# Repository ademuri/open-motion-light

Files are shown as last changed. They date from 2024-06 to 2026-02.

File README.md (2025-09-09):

# open-motion-light

A battery-powered motion sensor light.

Status: in development (as of July 2025). The current hardware revision, v1.2, mostly works, but has a few small issues. I'm hoping that the next revision will be the "final" version before starting small-scale production for sale.

Ordering and programming one of these units is a relatively complicated project. I don't recommend it unless you're looking for a learning experience, or have completed similar projects before.

## Programming

To easily update the firmware on your unit, and to configure the settings, go to the management page: https://ademuri.github.io/open-motion-light-manager/. This uses the WebSerial browser API, which is only supported in Chromium-based browsers (e.g. Chrome and Edge).

Otherwise, you can build the code yourself using PlatformIO. To build and upload, from the root of this directory run:

```bash
$ pio run -e default -t upload
```

## Firmware

The firmware for this project is written in C++ using the Arduino framework, and built using PlatformIO. It has comprehensive test coverage, which runs on the desktop (also using PlatformIO). You can run the tests with:

```bash
$ pio test -e native
```

### Architecture

Most use of hardware is wrapped in a hardware abstraction layer (HAL) - a thin wrapper class. This allows writing simple fakes for each of these interfaces, for use in tests. This means that the primary control logic is easily testable.

## Fabrication

This board is designed for PCB fabrication and assembly using JLC PCB. The relevant files are in `hardware/production`:

- `open-motion.light.zip` contains the Gerbers, for PCB assembly.
- `bom.csv` is the bill of materials, which contains the list of components.
- `positions.csv` is the positions file - it lists the exact position and orientation of all placed components.

### PCB parameters

Most of JLC's defaults for PCBs are fine. 1.6mm is the best size for this. White soldermask is preferred, since it reflects more light. I highly recommend selecting the 'LeadFree HASL' surface finish - better not to use lead, and it's only a small cost increase.

### Assembly parameters

This design requires PCBA Type 'Standard', since it needs assembly on both sides. Most of the components are on the top, except the USB port, battery holder, power switch, and reset button. For small quantities, this adds moderate cost, but the USB port would be difficult (although not impossible) to solder by hand. The rest of the parameters can be left as default.

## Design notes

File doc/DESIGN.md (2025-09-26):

# Design record

## Hardware v1.1 measurements - LED driver

Signal rise time is ~85ns, which is about 10MHz. No overshoot or ringing visible on a 50MHz scope.

At 3.5v, with main LED full on the board draws ~340mA. This increases to ~390mA at 3.2v, and ~440mA at 3.0v.

## Hardware v1.3 calculations

### PIR sensitivity adjust

The `SENS` pin is used to adjust the sensitivity of the motion sensor. 0V is maximum sensitivity, and 1/4 _ VDD is minimum. In this revision, the PIR is powered by a 3.0V LDO, so the minimum sensitivity will be at 1/4 _ 3.0V = 0.75V.

The PIR `SENS` pin has an equivalent 120kΩ pulldown (measured on two devices, pretty consistent, at least at the same temperature). I added a 1MΩ pulldown resistor to improve stability across PIR devices and temperatures. This pulldown likely comes from the PIR's internal ADC.

To allow adjusting sensitivity in software, three resistors are connected to the pulldown via MCU pins. These form a variable voltage divider. They're sized at 1MΩ and 2MΩ. This means that the possible resistance and voltage divider output values (at 3.4V battery level) are:

| Resistance | Output Voltage | Percent |
| --- | --- | --- |
| 2 MΩ | 173 mV | 23% |
| 1 MΩ | 329 mV | 44% |
| 667 kΩ | 470 mV | 63% |
| 400 kΩ | 718 mV | 96% |

There could be moderate variation in the PIR's equivalent pulldown between devices and at different temperatures. The sensitivity adjustment is pretty coarse anyway, so this is acceptable. If this does prove to be an issue, we could use a low-power voltage buffer, such as `TLV8541DBVR`, which consumes 500nA.

### Battery charger temperature sensor

The `BQ25170DSGR` uses an NTC thermistor to measure the temperature of the battery, and will only charge when the temperature is in a certain range. [The battery that I've used so far](https://www.batteryspace.com/LiFePO4-18650-Rechargeable-Cell-3.2V-1800-mAh.aspx) may be charged between 0°C and 50°C. Since the thermistor is just surface-mounted to the PCB, and not in direct contact with the battery, we'll adjust this range to roughly 5°C-45°C.

From [the charger IC datasheet](https://www.ti.com/lit/ds/symlink/bq25170.pdf), the nominal bias current is 38μA. `V_COLD` is 1.04V, and `V_HOT` is 188mV. So, the resistances we need are:

- Cold: `1.04V / 38μA = 27368Ω`
- Hot: `.188V / 38μA = 4947Ω`

If we use [this Sunlord 10k 3950K thermistor](https://jlcpcb.com/partdetail/Sunlord-SDNT1608X103F3950FTF/C279936), then it will yield the range 4°C-42°C - close enough!

We can disable charging by pulling the TS pin below 40mV (minimum). We'll connect this to an MCU pin. Most of the pins have 50nA leakage, which is negligible relative to the 38μA bias current. If we ignore the resistance of the thermistor, then we need `.04V / 38μA = 1052Ω` at most. So, if we use a 1kΩ resistor, it'll be sufficient.

### LED driver inductor selection

[From the datasheet](https://www.ti.com/lit/ds/symlink/tps61165.pdf), inductor peak-to-peak ripple is:

`I_P = 1 / (22uH * 1.2MHz * (1 / (19V + 0.4V - 3V) + 1 / 3V)) = 111mA`

assuming a 22nH inductor, and 3.6V input voltage (worst case). The following calculations assume 80% efficiency - the datasheet doesn't list the efficiency for 3V in, 19V out. But, for 5V in, 24V out at 48mA, the efficiency is ~89%. And, for 3V in, 12V out at 48mA, the efficiency is ~88%. So, actual efficiency should be closer to these values.

`I_out-max = 3V * (1.2A - 0.111A / 2) * 0.8 / 19V = 144.5 mA`

We're setting the output current to `48 mA`, so we're well within a safe margin.

`I_in-DC = 19V * .048A / (3V * 0.8) = 380 mA`

The inductor needs to be rated for a saturation current of greater than `380mA + 111mA / 2 = 436mA`.

### Part availability and sourcing

The previous revision used a few ICs from Chinese brands, which I couldn't find a source for other than LCSC. This presents moderate risk - if LCSC stops carrying them, then we'd need to use a different part, likely requiring a redesign.

#### USB-to-serial converter

The previous revision used the CH340X USB-to-UART serial converter chip. While this chip is commonly used, it is not available from Western retailers such as Digikey and Mouser. It _is_ available through LCSC, a reputable Chinese supplier. I found it at [another Chinese supplier, HQOnline](https://www.hqonline.com/product-detail/usb-chips-wch-ch340x-2500405741) - owned by NextPCB. While I'm not familiar with them, it's at least a second source. There is still some risk from using parts only available from Chinese distributors, such as from export restrictions or tariffs.

Sparkfun uses the CH340 series in some of their products - see [their guide on installing the drivers](https://learn.sparkfun.com/tutorials/how-to-install-ch340-drivers/all). This is a decent sign that it's available enough. I also found [this thread on EEVblog](https://www.eevblog.com/forum/beginners/ch340-ch330-for-commercial-crowdfunding-product/), where multiple people report using CH340s successfully in their projects.

An alternative would be the [Silicon Labs CP2102N](https://www.digikey.com/en/products/detail/silicon-labs/CP2102N-A02-GQFN28R/9863480). However, the chip is larger (QFN28 vs MSOP-10), and about twice the cost ($1.03 vs $0.39 at qty 100 from LCSC, at revision time).

#### 18650 battery holder

The design uses the [`BH-18650-A1AJ005` 18650 holder](https://jlcpcb.com/partdetail/MYOUNG-BH_18650A1AJ005/C5290176) from manufacturer MYOUNG. The only primary source I could find this from was LCSC. However, JLC doesn't currently list 18650 holders from any other manufacturers, so we'll stick with this as long as we're using JLC's turnkey assembly service. While it may take a layout update if we need to switch to a different holder, the functionality will not change, so this is lower risk.

#### Tactile switch

The design uses a tactile switch for the reset button. This shouldn't strictly be needed, since the CH340X can reset the MCU. However, it is nice to have, and is very cheap (about $0.02 each). This is available both from LCSC and HQOnline, and as with the battery holder, would be straightforward to replace if necessary.

#### White LEDs

As with the above parts, the white LEDs (`HL-AM-2835H421W-S1-08-HR3` from HONGLITRONIC) are not available from Western distributors. However, they are a common size (2835 metric) with common specs (~3.2V forward voltage, 60mA rated current), and [drop-in alternatives](https://www.digikey.com/en/products/detail/ams-osram-usa-inc/GW-JTLMS1-CM-G7H2-XX58-1-60-R33/13680961) are easily available from Western distributors.

#### PIR sensor

The design uses a PIR sensor, `XYC-PIR224S-S1` from NewOpto. This part is not available from Western distributors, and I couldn't find it from Asian distributors other than LCSC. If we limit this to only complete modules with a digital interface, then the cheapest Western-available part is the [ZiLOG `ZDP323`](https://www.mouser.com/ProductDetail/ZiLOG/ZDP323B1). As of writing, it is $2.57 each at qty 100, versus $0.47 each at qty 100 for the NewOpto. From what I can tell, using an analog sensor and implementing the supporting circuitry needed would be pretty complex, and not significantly cheaper anyway. So, we'll stick with the NewOpto for now, and revisit if it becomes a problem.

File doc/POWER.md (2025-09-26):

# Power

## Battery

By default, the MCU that we're using has brown-out reset (BOR) enabled, and configured to use a threshold from 2.54 to 2.74 V. This is documented in the programming manual (RM0377), in section `6.2.2 Brown out reset (BOR)`. Note that with regards to BOR, there are two versions of the processor: one which enables it by default at power-on time, and one which disables it. We want the former.

### Charging

On 2025-09-26, used a thermal camera to check battery charging with hardware v1.3. After about 10 minutes charging a depleted battery, measured a peak temperature of ~126F (52C) on top of the charger IC, and about 106F on the back side of the PCB.

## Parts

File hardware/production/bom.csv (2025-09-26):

Designator | Footprint | Quantity | Value | LCSC Part #
BT1 | BAT-TH_BH-18650-A1AJ005 | 1 | Battery_Cell | C5290176
C1, C13, C19 | 1206 | 3 | 47uF | C96123
C10, C20, C21, C24, C3, C4, C8 | 0603 | 7 | 10uF | C96446
C11 | 1206 | 1 | 4.7uF 50V | C51205
C12, C14, C15, C16, C17, C18, C2, C22, C23, C25, C26, C27, C28, C5, C6, C7, C9 | 0402 | 17 | 100nF | C307331
D1 | SOT-23-6 | 1 | SRV05-4-P-T7 | C85364
D13, D8 | D_SMA | 2 | D | C22452
D2, D3, D4 | 0603 | 3 | RED | C2286
D5, D6, D7 | D_SOD-523 | 3 | ESD5Z5.0 | C5199848
F1 | 1206 | 1 | BSMD1206-075-6V | C883127
FB1, FB2 | 1206 | 2 | 0R | C17888
J1 | HRO_TYPE-C-31-M-12 | 1 | TYPE-C-31-M-12 | C165948
L2 | L_Sunlord_SWPA4030S | 1 | 22uH | C83472
LED1, LED2, LED3, LED4, LED5, LED6 | LED-SMD_L3.3-W2.8-RD | 6 | HL-AM-2835H421W-S1-08-HR3 | C210315
R1 | 0603 | 1 | 620 | C23220
R11, R12, R3, R30, R31, R6, R7 | 0402 | 7 | 10k | C25744
R13, R14, R15, R16, R2, R26, R27, R34, R8, R9 | 0402 | 10 | 1k | C11702
R18 | 0402 | 1 | 100k | C25741
R19, R20, R23 | 0402 | 3 | 4k7 | C25900
R21, R28, R29, R35, R36 | 0603 | 5 | 2M | C22976
R24, R39 | 0402 | 2 | 22k | C25768
R25 | 0603 | 1 | 4Ω3 | C2933230
R37 | 0402 | 1 | 10 | C25077
R4, R5 | 0402 | 2 | 5k1 | C25905
R40, R41, R42 | 0603 | 3 | 1M | C22935
R43 | 0402 | 1 | 82k | C2909388
SW1 | SW_TACTILE_5.1MM_TS-1187A-C-D-B | 1 | SW_Push | C318884
SW3 | SW-SMD_SSSS213800 | 1 | SSSS213800 | C361168
TH1 | 0603 | 1 | Thermistor_NTC | C279936
U1 | Texas_DSG0008A_WSON-8-1EP_2x2mm_P0.5mm_EP0.9x1.6mm_ThermalVias | 1 | BQ25170DSGR | C5208201
U2 | SENSOR-SMD_VCNL4020-GS08 | 1 | VCNL4020-GS08 | C511034
U3 | WSON-6-1EP_2x2mm_P0.65mm_EP1x1.6mm_ThermalVias | 1 | TPS61165DRV | C122568
U4 | TO-5-4_BD9.2-P2.54_XYC-PIR224D-D0 | 1 | XYC-PIR224S-S1 | C6081347
U6 | MSOP-10_3x3mm_P0.5mm | 1 | CH340X | C3035748
U7 | QFN-32-1EP_5x5mm_P0.5mm_EP3.45x3.45mm | 1 | STM32L051K8Ux | C516778

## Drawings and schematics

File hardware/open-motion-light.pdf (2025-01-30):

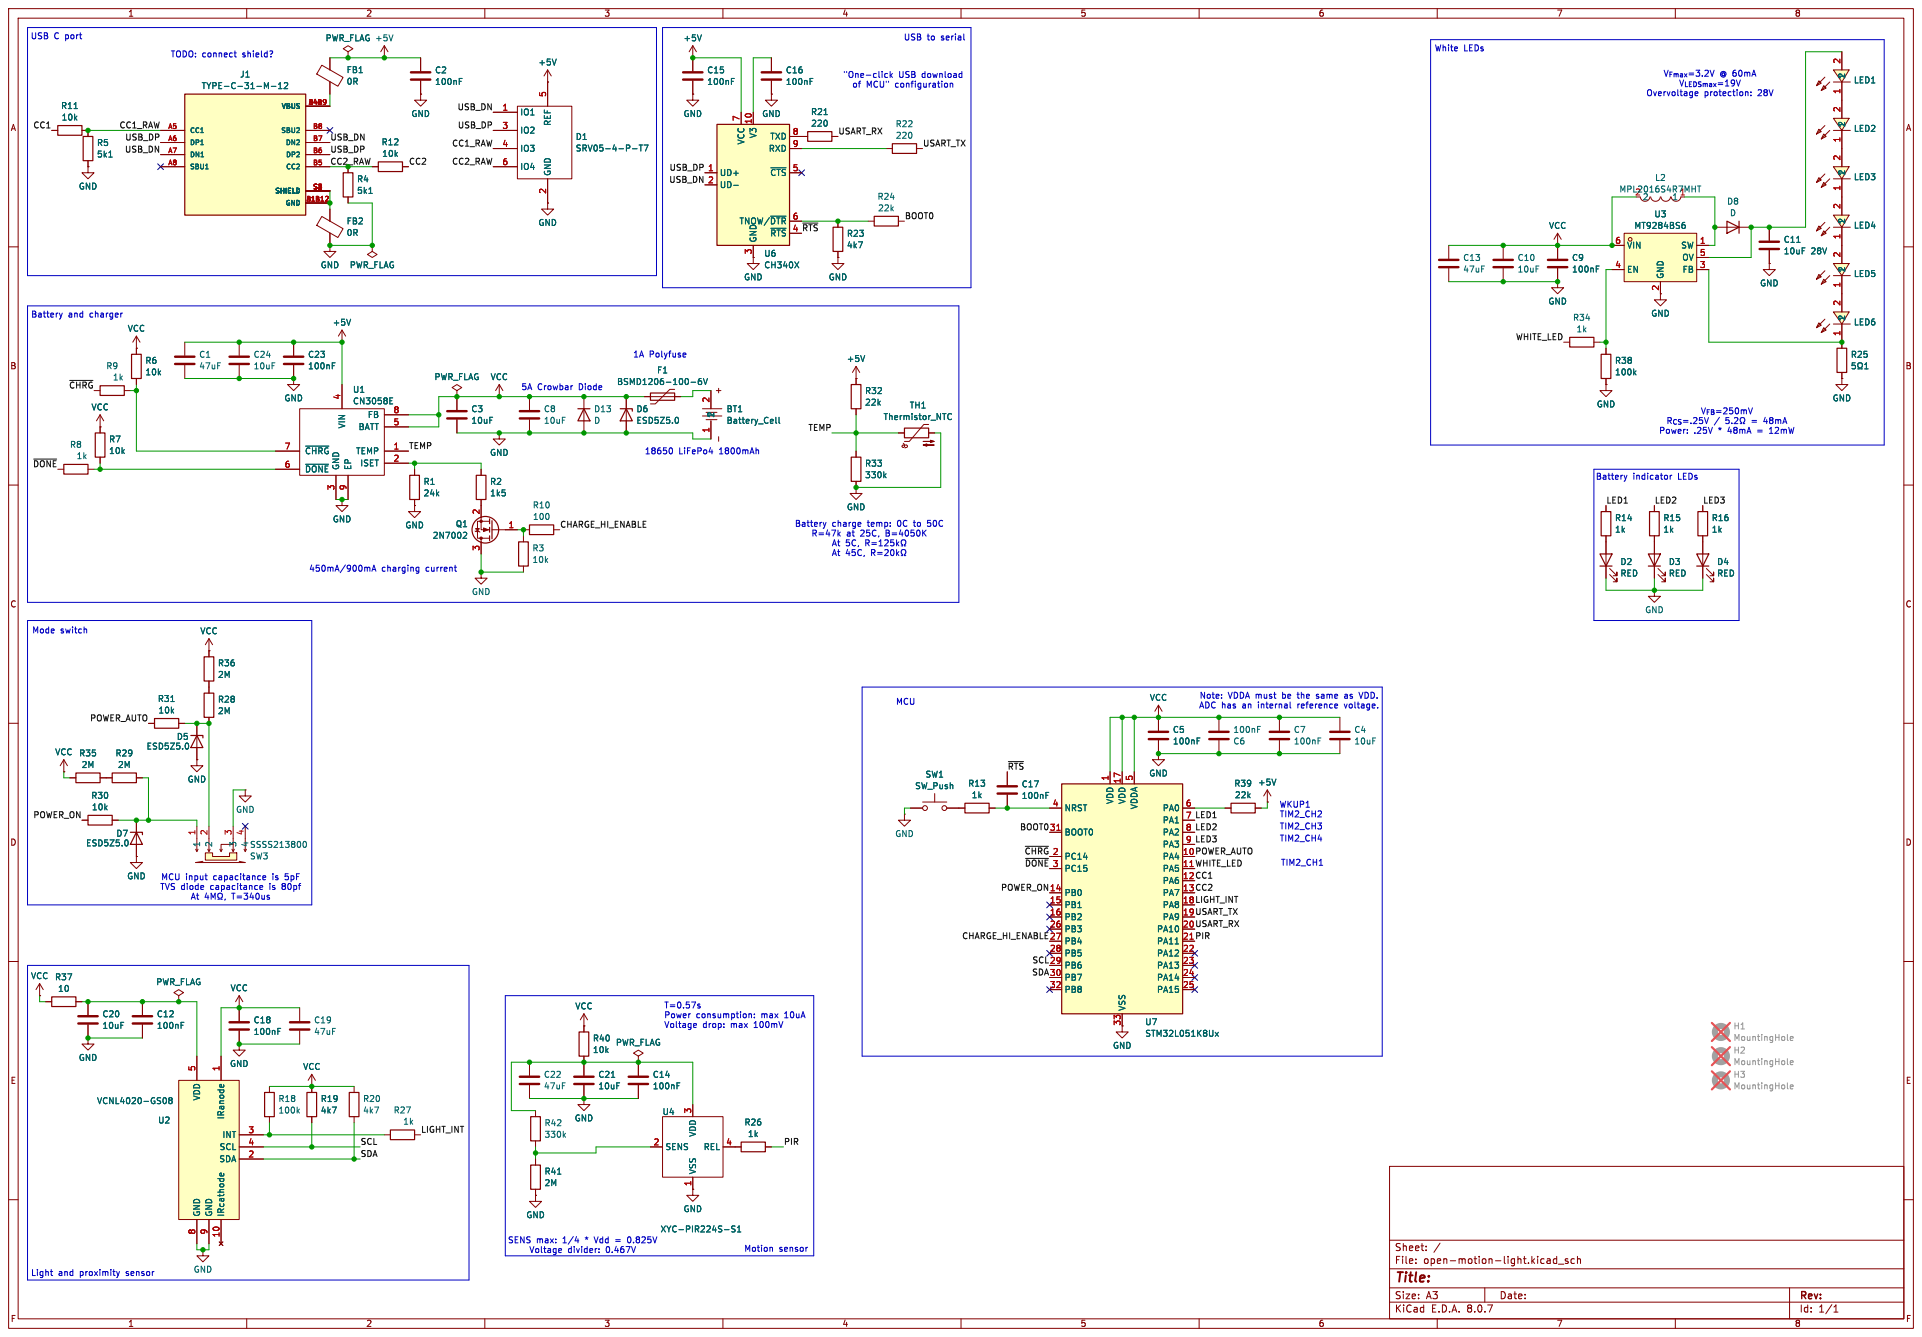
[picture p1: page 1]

of MCU" configuration USB to serial

3 ~{RTS}4 ~{CTS}5 TNOW/~{DTR}6 VCC

4 BATT 5 ~{DONE} 6 ~{CHRG} 7 FB 8 EP

Battery charge temp: 0C to 50C

1 PA4 10 PA5 11 PA6 12 PA7 13 PB0 14 PB1 15 PB2 16 VDD 17 PA8 18 PA9 19 PC14 2 PA10 20 PA11 21 PA12 22 PA13 23 PA14 24 PA15 25 PB3 26 PB4 27 PB5 28 PB6 29 PC15 3 PB7 30 BOOT0 31 PB8 32 VSS 33 NRST 4 VDDA

Id: 1/1 Title: File: open-motion-light.kicad_sch Sheet: /

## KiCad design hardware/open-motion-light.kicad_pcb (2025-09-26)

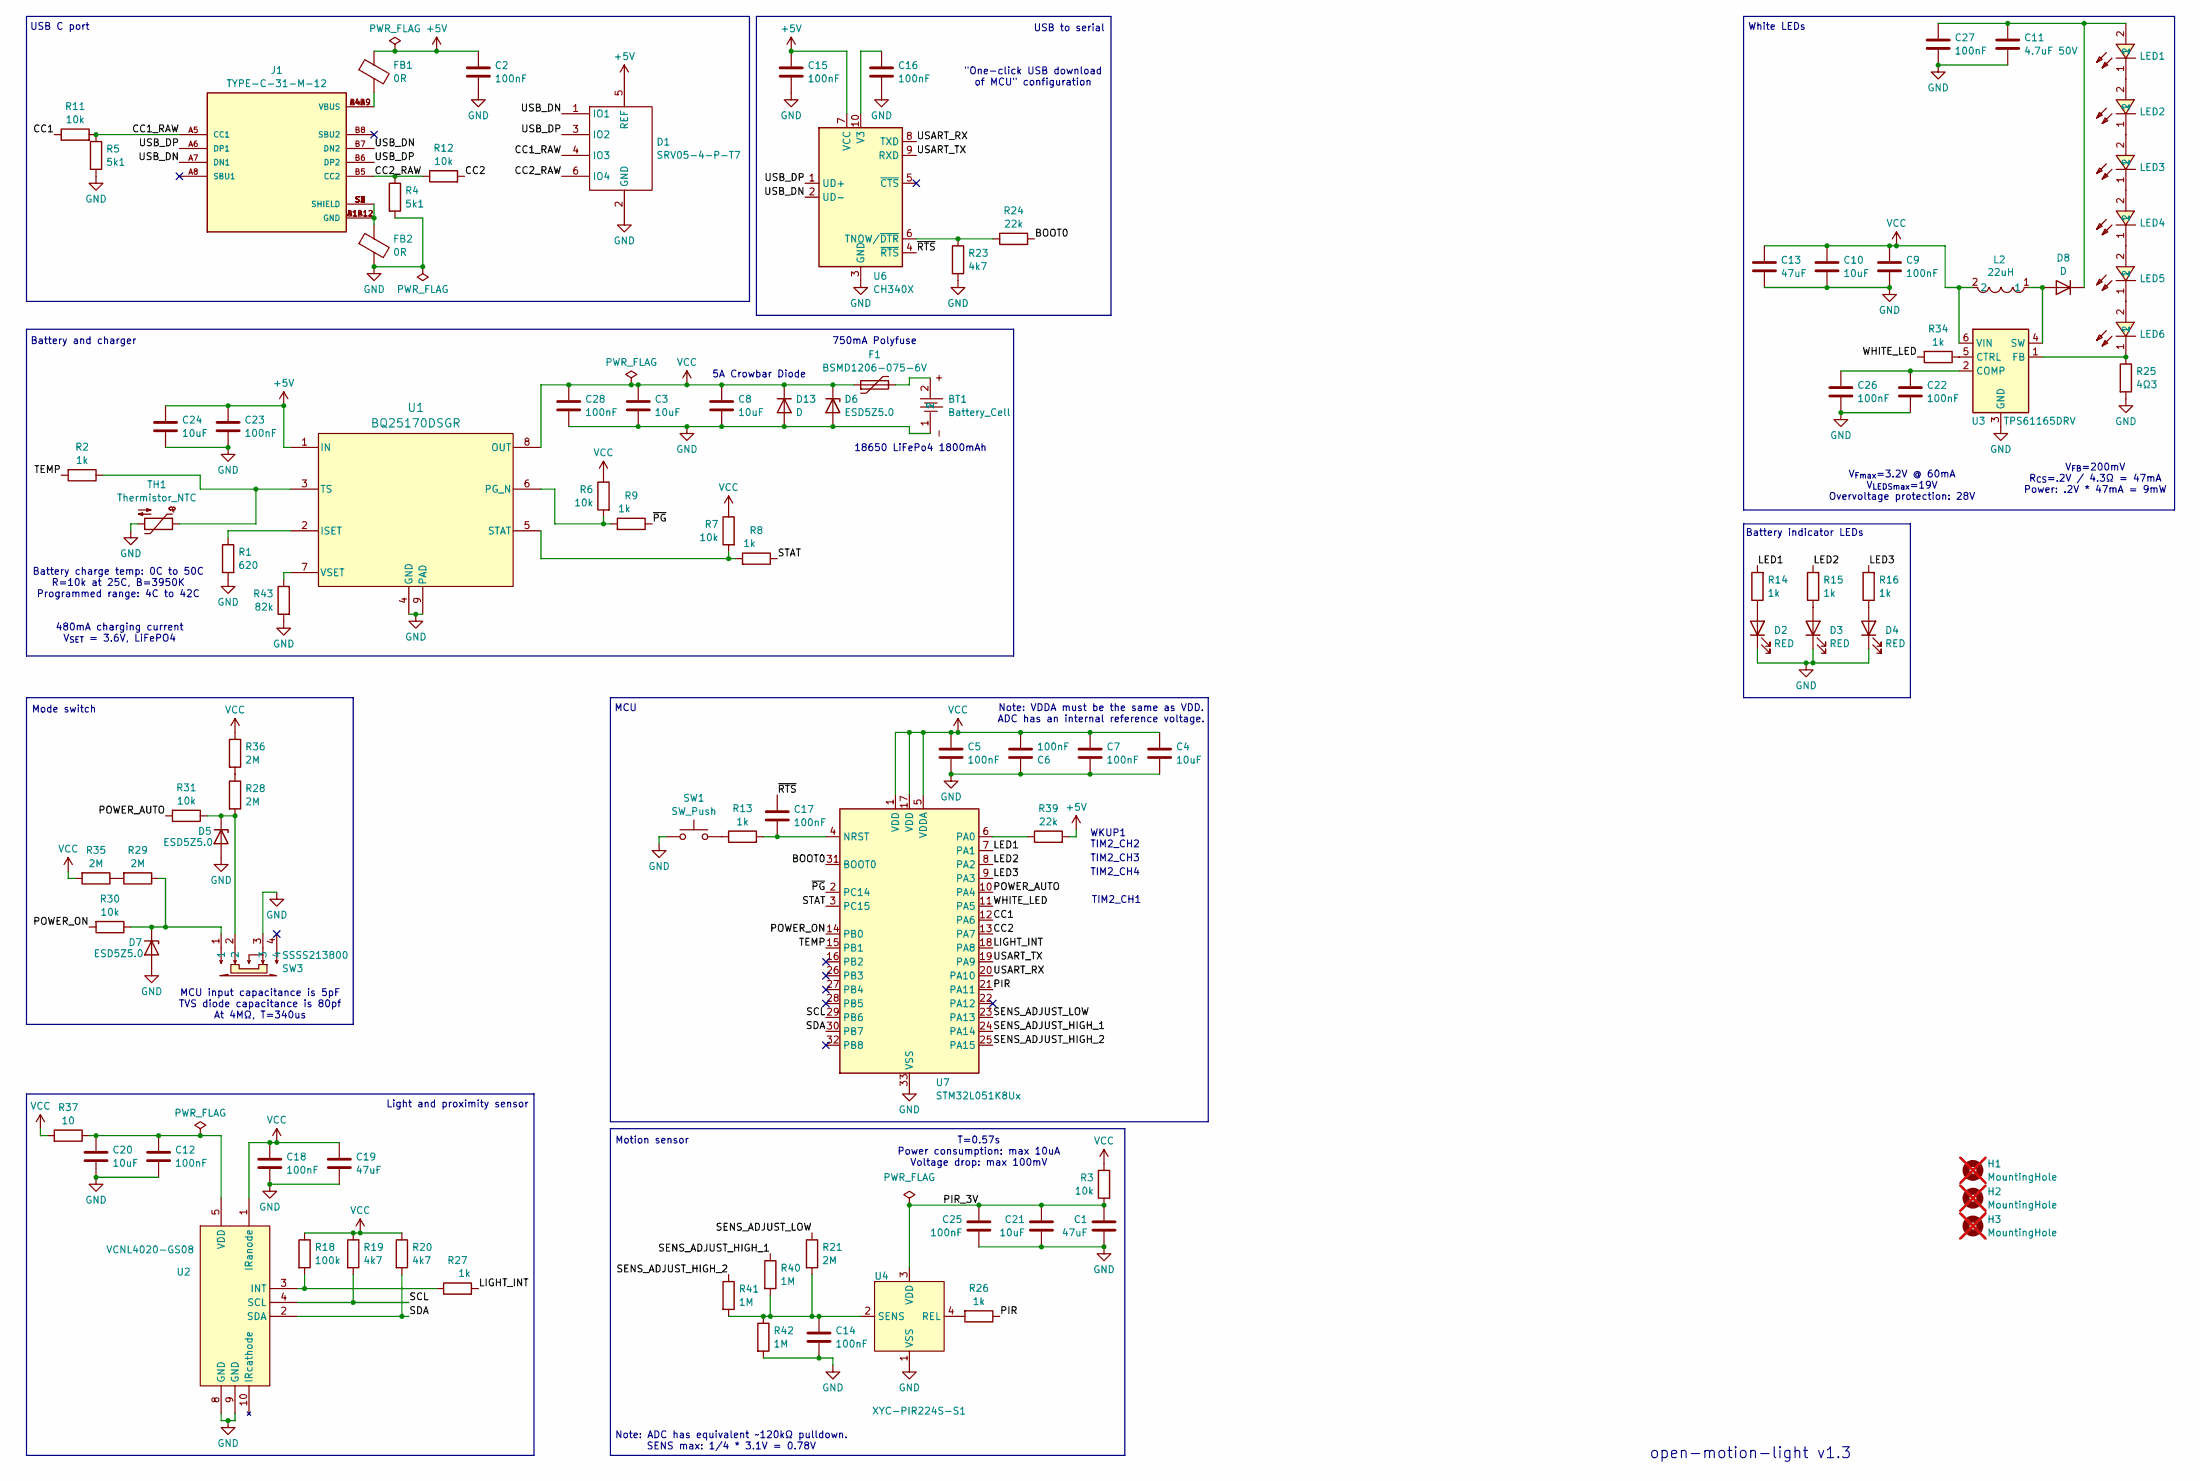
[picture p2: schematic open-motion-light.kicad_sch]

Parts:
BT1: Battery_Cell; BAT-TH_BH-18650-A1AJ005; LCSC Part C5290176
C1, C13, C19: 47uF; C_1206_3216Metric; LCSC C96123
C2, C5, C6, C7, C9, C12, C14, C15, C16, C17, C18, C22, C23, C25, C26, C27, C28: 100nF; C_0402_1005Metric; LCSC C307331
C3, C4, C8, C10, C20, C21, C24: 10uF; C_0603_1608Metric; LCSC C96446
C11: 4.7uF 50V; C_1206_3216Metric; LCSC C51205
D1: SRV05-4-P-T7; SOT-23-6; LCSC C85364
D2, D3, D4: RED; LED_0603_1608Metric; LCSC C2286
D5, D6, D7: ESD5Z5.0; D_SOD-523; LCSC C5199848
D8, D13: D; D_SMA; LCSC C22452
F1: BSMD1206-075-6V; Fuse_1206_3216Metric; LCSC C883127
FB1, FB2: 0R; L_1206_3216Metric; LCSC C17888
H1, H2, H3: MountingHole; MountingHole_3.2mm_M3_ISO7380; not fitted
J1: TYPE-C-31-M-12; HRO_TYPE-C-31-M-12; PARTREV A; LCSC C165948
L2: 22uH; L_Sunlord_SWPA4030S; LCSC Part C83472
LED1, LED2, LED3, LED4, LED5, LED6: HL-AM-2835H421W-S1-08-HR3; LED-SMD_L3.3-W2.8-RD; LCSC Part C210315
R1: 620; R_0603_1608Metric_Pad0.98x0.95mm_HandSolder; LCSC C23220
R2, R8, R9, R13, R14, R15, R16, R26, R27, R34: 1k; R_0402_1005Metric; LCSC C11702
R3, R6, R7, R11, R12, R30, R31: 10k; R_0402_1005Metric; LCSC C25744
R4, R5: 5k1; R_0402_1005Metric; LCSC C25905
R18: 100k; R_0402_1005Metric; LCSC C25741
R19, R20, R23: 4k7; R_0402_1005Metric; LCSC C25900
R21, R28, R29, R35, R36: 2M; R_0603_1608Metric; LCSC C22976
R24, R39: 22k; R_0402_1005Metric; LCSC C25768
R25: 4Ω3; R_0603_1608Metric; LCSC C2933230
R37: 10; R_0402_1005Metric; LCSC C25077
R40, R41, R42: 1M; R_0603_1608Metric; LCSC C22935
R43: 82k; R_0402_1005Metric; LCSC C2909388
SW1: SW_Push; SW_TACTILE_5.1MM_TS-1187A-C-D-B; LCSC C318884
SW3: SSSS213800; SW-SMD_SSSS213800; LCSC Part C361168
TH1: Thermistor_NTC; R_0603_1608Metric; LCSC C279936
U1: BQ25170DSGR; Texas_DSG0008A_WSON-8-1EP_2x2mm_P0.5mm_EP0.9x1.6mm_ThermalV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; LCSC C5208201
U2: VCNL4020-GS08; SENSOR-SMD_VCNL4020-GS08; LCSC Part C511034
U3: TPS61165DRV; WSON-6-1EP_2x2mm_P0.65mm_EP1x1.6mm_ThermalVias; LCSC C122568
U4: XYC-PIR224S-S1; TO-5-4_BD9.2-P2.54_XYC-PIR224D-D0; LCSC Part C6081347
U6: CH340X; MSOP-10_3x3mm_P0.5mm; LCSC C3035748
U7: STM32L051K8Ux; QFN-32-1EP_5x5mm_P0.5mm_EP3.45x3.45mm; LCSC C516778

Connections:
+5V: C2.1, C15.1, C23.2, C24.1, D1.5 (REF), FB1.1, R39.2, U1.1 (IN), U6.7 (VCC)
/BOOT0: R24.2, U7.31 (BOOT0)
/CC1: R11.1, U7.12 (PA6)
/CC1_RAW: D1.4 (IO3), J1.A5 (CC1), R5.1, R11.2
/CC2: R12.2, U7.13 (PA7)
/CC2_RAW: D1.6 (IO4), J1.B5 (CC2), R4.1, R12.1
/LED1: R14.2, U7.7 (PA1)
/LED2: R15.2, U7.8 (PA2)
/LED3: R16.2, U7.9 (PA3)
/LIGHT_INT: R27.2, U7.18 (PA8)
/PIR: R26.1, U7.21 (PA11)
/PIR_3V: C1.2, C21.1, C25.1, R3.2, U4.3 (VDD)
/POWER_AUTO: R31.2, U7.10 (PA4)
/POWER_ON: R30.2, U7.14 (PB0)
/SCL: R19.2, U2.4 (SCL), U7.29 (PB6)
/SDA: R20.2, U2.2 (SDA), U7.30 (PB7)
/SENS_ADJUST_HIGH_1: R40.1, U7.24 (PA14)
/SENS_ADJUST_HIGH_2: R41.1, U7.25 (PA15)
/SENS_ADJUST_LOW: R21.1, U7.23 (PA13)
/STAT: R8.1, U7.3 (PC15)
/TEMP: R2.2, U7.15 (PB1)
/USART_RX: U6.8 (TXD), U7.20 (PA10)
/USART_TX: U6.9 (RXD), U7.19 (PA9)
/USB_DN: D1.1 (IO1), J1.A7 (DN1), J1.B7 (DN2), U6.2 (UD-)
/USB_DP: D1.3 (IO2), J1.A6 (DP1), J1.B6 (DP2), U6.1 (UD+)
/WHITE_LED: R34.2, U7.11 (PA5)
/~PG: R9.1, U7.2 (PC14)
/~RTS: C17.1, U6.4 (~RTS)
GND: BT1.1, C1.1, C2.2, C3.2, C4.2, C5.2, C6.1, C7.2, C8.2, C9.2, C10.2, C11.2, C12.1, C13.1, C14.2, C15.2, C16.2, C18.1, C19.1, C20.2, C21.2, C22.2, C23.1, C24.2, C25.2, C26.2, C27.2, C28.1, D1.2 (GND), D2.1 (K), D3.1 (K), D4.1 (K), D5.2 (A), D6.2 (A), D7.2 (A), D13.2 (A), FB2.2, R1.2, R4.2, R5.2, R23.2, R25.2, R42.2, R43.2, SW1.1, SW3.3, TH1.2, U1.4 (GND), U1.9 (PAD), U2.8 (GND), U2.9 (GND), U3.3 (GND), U3.7 (GND), U4.1 (VSS), U6.3 (GND), U7.33 (VSS)
unnamed: BT1.2, F1.2
unnamed: D2.2 (A), R14.1
unnamed: D3.2 (A), R15.1
unnamed: D4.2 (A), R16.1
unnamed: D5.1 (K), R28.2, R31.1, SW3.2
unnamed: D7.1 (K), R29.1, R30.1, SW3.1
unnamed: D8.2 (A), L2.1, U3.4 (SW)
unnamed: C11.1, C27.1, D8.1 (K), LED1.2
unnamed: FB1.2, J1.A4B9 (VBUS), J1.B4A9 (VBUS)
unnamed: FB2.1, J1.A1B12 (GND), J1.B1A12 (GND), J1.S1 (SHIELD), J1.S2 (SHIELD), J1.S3 (SHIELD), J1.S4 (SHIELD)
unnamed: LED1.1, LED2.2
unnamed: LED2.1, LED3.2
unnamed: LED3.1, LED4.2
unnamed: LED4.1, LED5.2
unnamed: LED5.1, LED6.2
unnamed: R13.1, SW1.2
unnamed: R28.1, R36.2
unnamed: R29.2, R35.1
unnamed: R1.1, U1.2 (ISET)
unnamed: R6.2, R9.2, U1.6 (PG_N)
unnamed: R7.2, R8.2, U1.5 (STAT)
unnamed: R2.1, TH1.1, U1.3 (TS)
unnamed: R43.1, U1.7 (VSET)
unnamed: R18.2, R27.1, U2.3 (INT)
unnamed: C12.2, C20.1, R37.1, U2.5 (VDD)
unnamed: C22.1, C26.1, U3.2 (COMP)
unnamed: R34.1, U3.5 (CTRL)
unnamed: LED6.1, R25.1, U3.1 (FB)
unnamed: R26.2, U4.4 (REL)
unnamed: C14.1, R21.2, R40.2, R41.2, R42.1, U4.2 (SENS)
unnamed: R23.1, R24.1, U6.6 (TNOW/~DTR)
unnamed: C16.1, U6.10 (V3)
unnamed: C17.2, R13.2, U7.4 (NRST)
unnamed: R39.1, U7.6 (PA0)
VCC: C3.1, C4.1, C5.1, C6.2, C7.1, C8.1, C9.1, C10.1, C13.2, C18.2, C19.2, C28.2, D6.1 (K), D13.1 (K), F1.1, L2.2, R3.1, R6.1, R7.1, R18.1, R19.1, R20.1, R35.2, R36.1, R37.2, U1.8 (OUT), U2.1 (IRanode), U3.6 (VIN), U7.1 (VDD), U7.5 (VDDA), U7.17 (VDD)

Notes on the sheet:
TIM2_CH1
V_{FB}=200mV R_{CS}=.2V / 4.3Ω = 47mA Power: .2V * 47mA = 9mW
Battery and charger
V_{Fmax}=3.2V @ 60mA V_{LEDSmax}=19V Overvoltage protection: 28V
White LEDs
"One-click USB download of MCU" configuration
USB C port
T=0.57s Power consumption: max 10uA Voltage drop: max 100mV
TIM2_CH2
Light and proximity sensor
TIM2_CH4
Battery charge temp: 0C to 50C R=10k at 25C, B=3950K Programmed range: 4C to 42C
480mA charging current V_{SET} = 3.6V, LiFePO4
open-motion-light v1.3
5A Crowbar Diode
18650 LiFePo4 1800mAh
WKUP1
TIM2_CH3
750mA Polyfuse
Mode switch
USB to serial
Note: ADC has equivalent ~120kΩ pulldown. SENS max: 1/4 * 3.1V = 0.78V
Note: VDDA must be the same as VDD. ADC has an internal reference voltage.
Battery indicator LEDs
MCU
Motion sensor
MCU input capacitance is 5pF TVS diode capacitance is 80pf At 4MΩ, T=340us

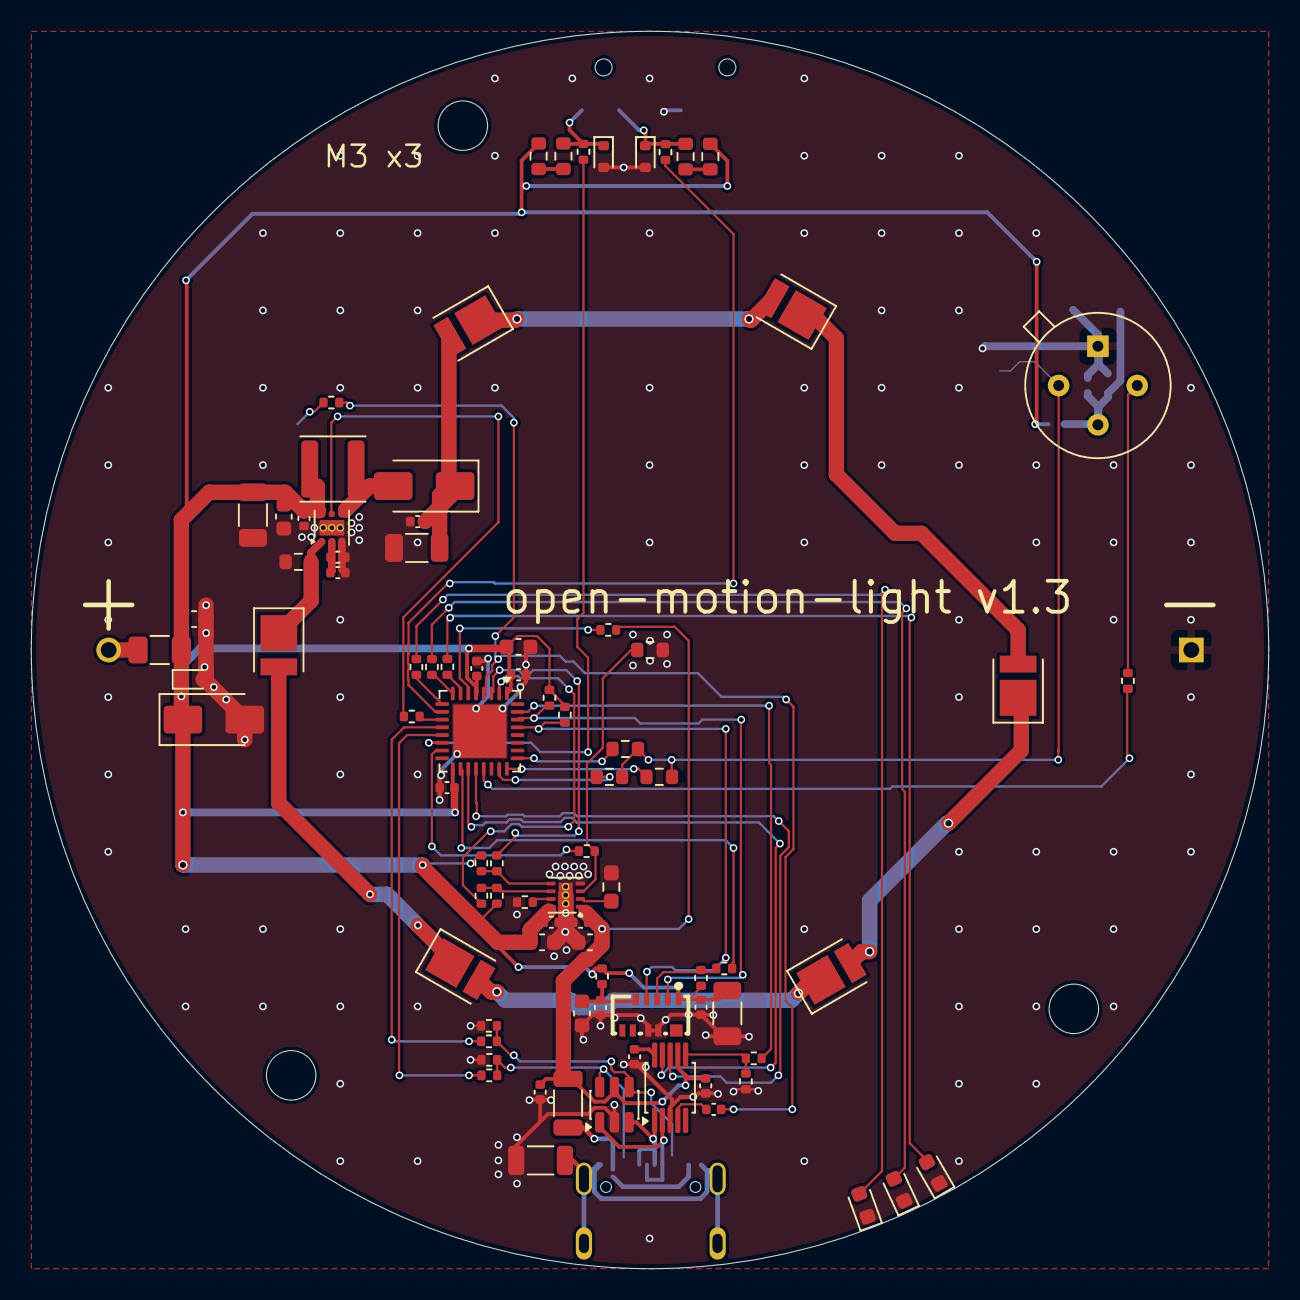
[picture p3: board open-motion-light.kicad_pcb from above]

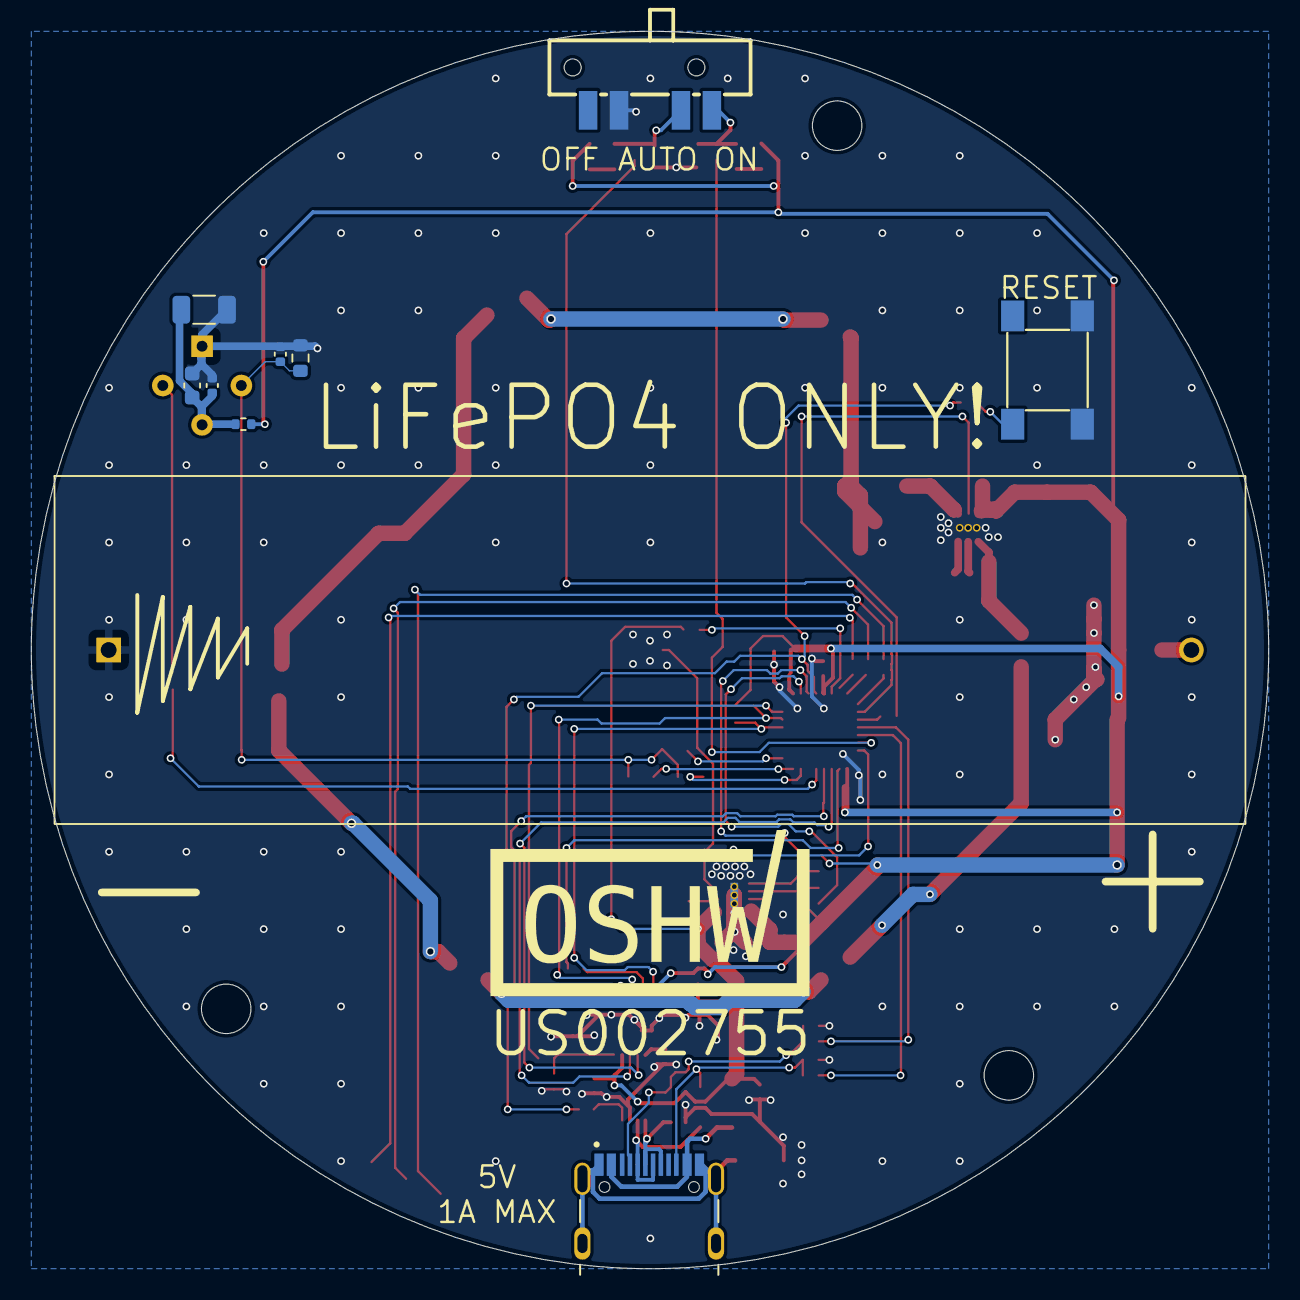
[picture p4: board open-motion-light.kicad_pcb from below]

Board: 4 copper layers, 80.0 x 80.0 mm, 98 parts (10 on the bottom side), 64 nets.

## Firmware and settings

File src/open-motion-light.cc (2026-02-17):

// Copyright 2024 Google LLC
//
// Licensed under the Apache License, Version 2.0 (the "License");
// you may not use this file except in compliance with the License.
// You may obtain a copy of the License at
//
//     http://www.apache.org/licenses/LICENSE-2.0
//
// Unless required by applicable law or agreed to in writing, software
// distributed under the License is distributed on an "AS IS" BASIS,
// WITHOUT WARRANTIES OR CONDITIONS OF ANY KIND, either express or implied.
// See the License for the specific language governing permissions and
// limitations under the License.

#include <Arduino.h>
#include <Wire.h>
#include <arduino-timer.h>
#include <edge-filter.h>

#include "arduino-serial-port.h"
#include "arduino-vcnl4020.h"
#include "clock.h"
#include "controller.h"
#include "internal-temperature-sensor.h"
#include "pins.h"
#include "serial-manager.h"
#include "stm32-power-controller.h"

// These enable printing values for the VCNL4020 to the serial console.
// #define DEBUG_VCNL4020_BRIGHTNESS
// #define DEBUG_VCNL4020_PROXIMITY

CountDownTimer vncl4020_timer{200};

InternalTemperatureSensor temperature_sensor;
ArduinoVCNL4020 vcnl4020;
Stm32PowerController power_controller;
Controller controller{&temperature_sensor, &vcnl4020, &power_controller};

ArduinoSerialPort serial_port;
SerialManager serial_manager{&serial_port, &controller};

#ifdef DEBUG_VCNL4020_PROXIMITY
constexpr uint16_t proximity_threshold = 5;
EdgeFilter proximity_edge_filter([]() { return vcnl4020.ReadProximity(); },
                                 /*alpha=*/255);
#endif  // DEBUG_VCNL4020_PROXIMITY

static void ErrorFlash(uint32_t period) {
  while (true) {
    uint8_t brightness = (millis() / period) % 2;
    analogWrite(kPinBatteryLed1, brightness);
    analogWrite(kPinBatteryLed2, brightness);
    analogWrite(kPinBatteryLed3, brightness);
  }
}

void setup() {
  Serial1.begin(115200);
  // Serial1.println("Booting...");

  // I2C - used for light sensor
  Wire.setSCL(kPinScl);
  Wire.setSDA(kPinSda);
  Wire.begin();
  Wire.setClock(400 * 1000);

  // From the datasheet for the MT9284BS6 LED driver, its recommended PWM
  // frequency is 20kHz < n < 1MHz.
  analogWriteFrequency(20 * 1000);
  analogWriteResolution(8);

  if (!serial_manager.Init()) {
    ErrorFlash(100);
  }

#ifdef DEBUG_VCNL4020_BRIGHTNESS
  vcnl4020.SetPeriodicAmbient(true);
  vncl4020_timer.Reset();
#endif  // DEBUG_VCNL4020_BRIGHTNESS

#ifdef DEBUG_VCNL4020_PROXIMITY
  vcnl4020.SetPeriodicProximity(true);
  vncl4020_timer.Reset();
#endif  // DEBUG_VCNL4020_PROXIMITY

  digitalWrite(kPinBatteryLed2, true);
  delay(100);
  digitalWrite(kPinBatteryLed2, false);
}

void loop() {
  controller.Step();
  serial_manager.Step();

#ifdef DEBUG_VCNL4020_BRIGHTNESS
  if (vncl4020_timer.Expired()) {
    if (vcnl4020.AmbientReady()) {
      Serial1.printf("ambient: %5u\n", vcnl4020.ReadAmbient());
    }
    vncl4020_timer.Reset();
  }
#endif  // ifdef DEBUG_VCNL4020_BRIGHTNESS

#ifdef DEBUG_VCNL4020_PROXIMITY
  // if (vcnl4020.ProximityReady()) {
  //   proximity_edge_filter.Run();
  //   Serial1.printf("rising: %u, falling: %u, value: %u, slope: %d\n",
  //                  edge_filter.Rising(proximity_threshold),
  //                  edge_filter.Falling(proximity_threshold),
  //                  edge_filter.GetFilteredValue(), edge_filter.Slope());
  // }
  if (vcnl4020.ProximityReady()) {
    Serial1.printf("proximity: %5u\n", vcnl4020.ReadProximity());
  }
#endif  // ifdef DEBUG_VCNL4020_PROXIMITY
}

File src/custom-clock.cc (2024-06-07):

#include "custom-clock.h"

#ifdef CUSTOM_CLOCK

#include "stm32l0xx_hal.h"

void Error_Handler() {
  __disable_irq();
  while (1);
}

// Generated using STM32Cube IDE. Sets the clock to use the MSI at 1MHz.
// According to STM32Cube's power calculator, the processor should consume about
// 230uA with this configuration.
// If you change the clock rate, also update the value of F_CPU in
// platformio.ini.
void SystemClock_Config() {
  RCC_OscInitTypeDef RCC_OscInitStruct = {0};
  RCC_ClkInitTypeDef RCC_ClkInitStruct = {0};

  /** Configure the main internal regulator output voltage
   */
  __HAL_PWR_VOLTAGESCALING_CONFIG(PWR_REGULATOR_VOLTAGE_SCALE1);

  /** Initializes the RCC Oscillators according to the specified parameters
   * in the RCC_OscInitTypeDef structure.
   */
  RCC_OscInitStruct.OscillatorType = RCC_OSCILLATORTYPE_MSI;
  RCC_OscInitStruct.MSIState = RCC_MSI_ON;
  RCC_OscInitStruct.MSICalibrationValue = 0;
  RCC_OscInitStruct.MSIClockRange = RCC_MSIRANGE_5;
  RCC_OscInitStruct.PLL.PLLState = RCC_PLL_NONE;
  if (HAL_RCC_OscConfig(&RCC_OscInitStruct) != HAL_OK) {
    Error_Handler();
  }

  /** Initializes the CPU, AHB and APB buses clocks
   */
  RCC_ClkInitStruct.ClockType = RCC_CLOCKTYPE_HCLK | RCC_CLOCKTYPE_SYSCLK |
                                RCC_CLOCKTYPE_PCLK1 | RCC_CLOCKTYPE_PCLK2;
  RCC_ClkInitStruct.SYSCLKSource = RCC_SYSCLKSOURCE_MSI;
  RCC_ClkInitStruct.AHBCLKDivider = RCC_SYSCLK_DIV1;
  RCC_ClkInitStruct.APB1CLKDivider = RCC_HCLK_DIV1;
  RCC_ClkInitStruct.APB2CLKDivider = RCC_HCLK_DIV1;

  if (HAL_RCC_ClockConfig(&RCC_ClkInitStruct, FLASH_LATENCY_0) != HAL_OK) {
    Error_Handler();
  }
}

#endif  // ifdef CUSTOM_CLOCK

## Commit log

2024-04-07 Start schematic - add USB port and charge controller
    [open-motion-light.kicad_pcb, open-motion-light.kicad_sch]
2024-04-07 Add input protection to USB and charger
    [open-motion-light.kicad_sch]
2024-04-07 Add LEDs and uC
    [open-motion-light.kicad_sch]
2024-04-08 Add battery protection
    [open-motion-light.kicad_sch]
2024-04-11 Start adding MT9284 LED driver
    [open-motion-light.kicad_sch]
2024-04-12 Finish LED driver. Add motion sensor and PIR.
    [open-motion-light.kicad_sch]
2024-04-12 Update processor to STM32L031G6Ux. Add CH340x. Organize some blocks.
    [open-motion-light.kicad_sch]
2024-04-14 First draft of schematic completed
    [open-motion-light.kicad_sch]
2024-04-14 Assign LCSC part numbers and footprints
    [open-motion-light.kicad_sch]
2024-04-16 Start placing components
    [open-motion-light.kicad_pcb, open-motion-light.kicad_sch]
2024-04-20 Migrate three resistors to basic components, continue placement
    [open-motion-light.kicad_pcb, open-motion-light.kicad_sch]
2024-04-28 Continue placement
    [open-motion-light.kicad_pcb, open-motion-light.kicad_sch]
2024-04-29 Finish placement
    [open-motion-light.kicad_pcb, open-motion-light.kicad_sch]
2024-04-29 First pass at routing
    [open-motion-light.kicad_pcb, open-motion-light.kicad_sch]
2024-04-29 Add lots of stitching vias
    [open-motion-light.kicad_pcb]
2024-04-29 Hardware revision v1.0
    [open-motion-light.kicad_pcb, open-motion-light.kicad_sch]
2024-04-30 Add empty PIO project with board definition
2024-04-30 Add pin definitions and mode setting
2024-05-03 Start adding controller: add power mode management
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2024-05-03 Cleanup: rename battery functions and remove uneeded variable
2024-05-04 Add library for VCNL4010 ambient light and proximity sensor
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2024-05-04 Add logic for PowerStatus
    [open-motion-light.kicad_sch]
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2024-05-04 Add handling for charger error
    [controller-test.cc]
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2024-05-07 Testing updates: reduce PWM frequency and tune some values
2024-05-07 Fix controller test for battery LED workaround
    [controller-test.cc]
2024-05-07 Add test coverage that ALS+Prox sensor is initialized
2024-05-09 Update schematic for v1.1
    [open-motion-light.kicad_sch]
2024-05-13 WIP start designing enclosure for v1.0
    [enclosure.FCStd]
2024-05-14 Add cutouts to enclosure bottom
    [enclosure.FCStd]
2024-05-15 Add switch boot and snap fit pockets
    [enclosure.FCStd]
2024-05-15 Add fillets and chamfers
    [enclosure.FCStd]
2024-05-15 Start fixing topological naming issues
    [bottom.step, enclosure.FCStd, switch plate.step]
2024-05-15 Complete TNP updates
    [enclosure.FCStd]
2024-05-16 First pass at cover
    [enclosure.FCStd, top.step]
2024-05-17 More v1.1 schematic updates
    [open-motion-light.kicad_pcb, open-motion-light.kicad_sch]
2024-05-21 Start updating placement and routing for v1.1
    [open-motion-light.kicad_pcb, open-motion-light.kicad_sch]
2024-05-21 Continue enclosure design
    [enclosure.FCStd]
2024-05-26 Re-organize schematic
    [open-motion-light.kicad_sch]
2024-05-27 Update PCB for circle layout
    [open-motion-light.kicad_pcb, open-motion-light.kicad_sch]
2024-05-29 Place and route LEDs, driver, and USB power
    [open-motion-light.kicad_pcb]
2024-05-30 Hardware revision v1.1
    [bom.csv, designators.csv, open-motion-light.kicad_pcb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]
2024-06-07 Move clock to custom-clock to avoid conflict with platform lib
    [custom-clock.cc]
2024-06-07 Add JLC part number for light sensor
    [open-motion-light.kicad_sch]
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2024-06-07 Add note about updating local version of Arduino
2024-06-07 Use analogWrite for all battery LEDs, and init 5v detect pin
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2024-06-13 Fix test for VCNL v1.1 change
    [controller-test.cc]
2024-06-13 Ignore motion sensor right after changing the main LED
2024-06-13 Go to stop mode when the LED is off
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2024-06-16 Don't turn on the main LED when charging but below cutoff
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2024-06-16 Prevent white LED flash on startup
    [open-motion-light.cc]
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2024-06-19 Fix board definition hack in readme
2024-06-21 Migrate the VCNL4020 sensor code to use the Wire interface directly.
    This replaces the Adafruit library.
    [open-motion-light.cc]
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2024-08-30 Increase sleep lockout timer.
    This fixes a bug where the LED sometimes does not turn on when switching
    from on to auto.
2024-09-05 Start updating schematic for v1.2
    [open-motion-light.kicad_pcb, open-motion-light.kicad_sch]
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2024-10-26 Fix sleep mode power consumption
2024-12-25 Fast blink status LEDs on charge error
2024-12-31 Tentative hardware v1.2
    [bom.csv, designators.csv, open-motion-light.kicad_pcb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]
2025-01-03 v1.2: remove PIR pulldown
    [open-motion-light.kicad_pcb, open-motion-light.kicad_sch]
2025-01-30 Hardware v1.2
    [bom.csv, designators.csv, open-motion-light.kicad_pcb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]
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2025-02-01 Fix showing battery status immediately on plugging in
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2025-02-03 Update PCB STEP file for v1.2
    [enclosure.FCStd]
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2025-02-03 Update USB-C port 3D model
    [open-motion-light.kicad_pcb]
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2025-02-12 WIP go into stop mode when the battery is low
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2025-04-05 Change battery voltage to be millivolts/int in the proto
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2025-04-05 Include the current config in the serial response
2025-04-08 Fix arduino build; actually save config
2025-04-16 Add prox and ALS sensor readings to status proto
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2025-05-17 Fix LED ramp to use periods > duty cycles
2025-08-28 Hardware v1.3 first pass
    [open-motion-light.kicad_pcb, open-motion-light.kicad_sch]
2025-09-09 WIP start updating for sourcing
    [open-motion-light.kicad_pcb, open-motion-light.kicad_sch]
2025-09-09 Convert to KiCAD v9
    [open-motion-light.kicad_pcb, open-motion-light.kicad_sch]
2025-09-09 Schematic updates for v1.3 (again)
    [open-motion-light.kicad_sch]
2025-09-26 Hardware v1.3 final
    [bom.csv, designators.csv, open-motion-light.kicad_pcb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]
2025-09-26 Add note on thermal performance of battery charger IC
2025-10-04 Update fake pin config values to match STM32
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2026-02-16 Update battery charging logic for v1.3 battery charger IC
2026-02-16 Don't sleep for the first second of turning on.
    This fixes an issue in the firmware where the device wouldn't respond on
    the serial port for about a minute after plugging it in.
    [controller-test.cc]
2026-02-16 Don't sleep when USB connected or 5V detected
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2026-09-06 Fix compatbility with ArduinoCore-API
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
